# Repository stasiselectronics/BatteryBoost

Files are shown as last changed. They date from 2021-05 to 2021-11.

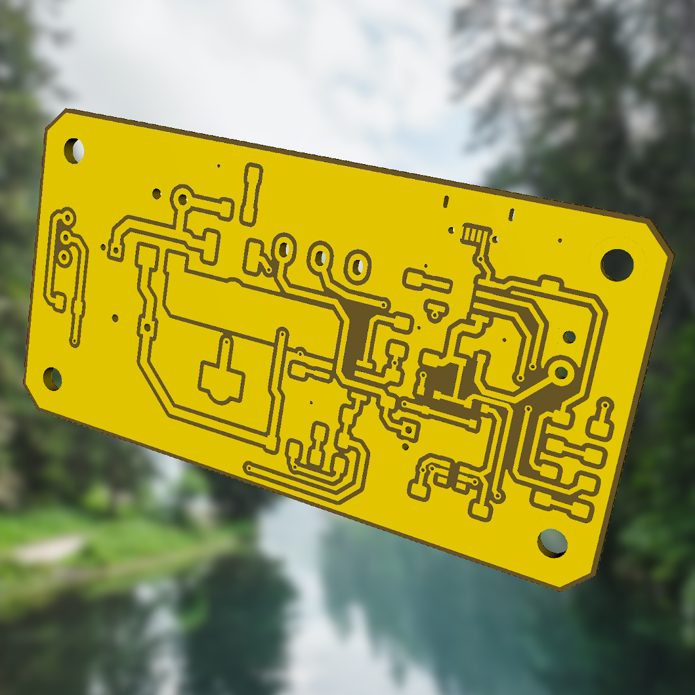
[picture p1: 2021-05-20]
Images/Renders/2021.05.17/2021_05_17_4.png

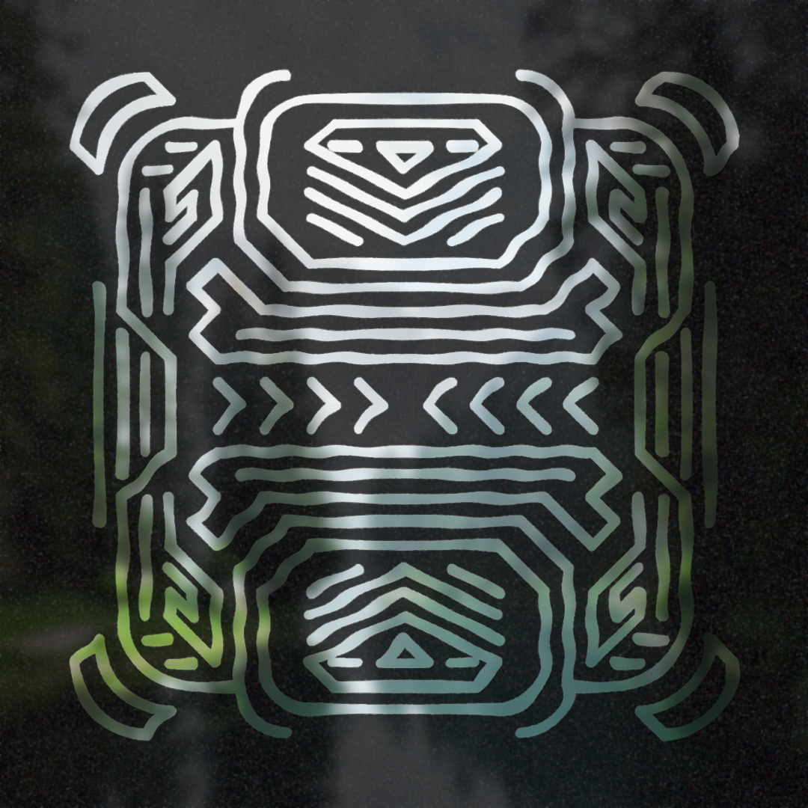
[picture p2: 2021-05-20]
Images/Renders/2021.05.17/2021_05_17_0.png

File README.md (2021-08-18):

# Battery Boost Module
<h3>3.7 V input, 5V-24V output</h3>

This respository contains the source files for a boost circuit designed to boost the voltage from a lithium battery to anywhere between 5 and 24 Volts.

The module includes a battery management system to help make recharging as easy as plugging in the microUSB cable.

## KiCAD

This board has been designed in KiCAD, the wonderful open-source Electronics CAD software!

[Learn More About KiCAD](https://www.kicad.org/about/kicad/)

## Project Status

I have written an [article on Hackster](https://www.hackster.io/stasiselectronics/lithium-battery-voltage-boost-module-5ba98e) to explain some of the lessons learned while working on this design.

I still have some testing to do and write about, so stay tuned for that!

I also intend on creating a documentation companion site hosted on this repo's github page.

Be sure to check out my instagram page for more frequent updates!

[Stasis Electronics on Instagram](https://www.instagram.com/stasis.electronics/)

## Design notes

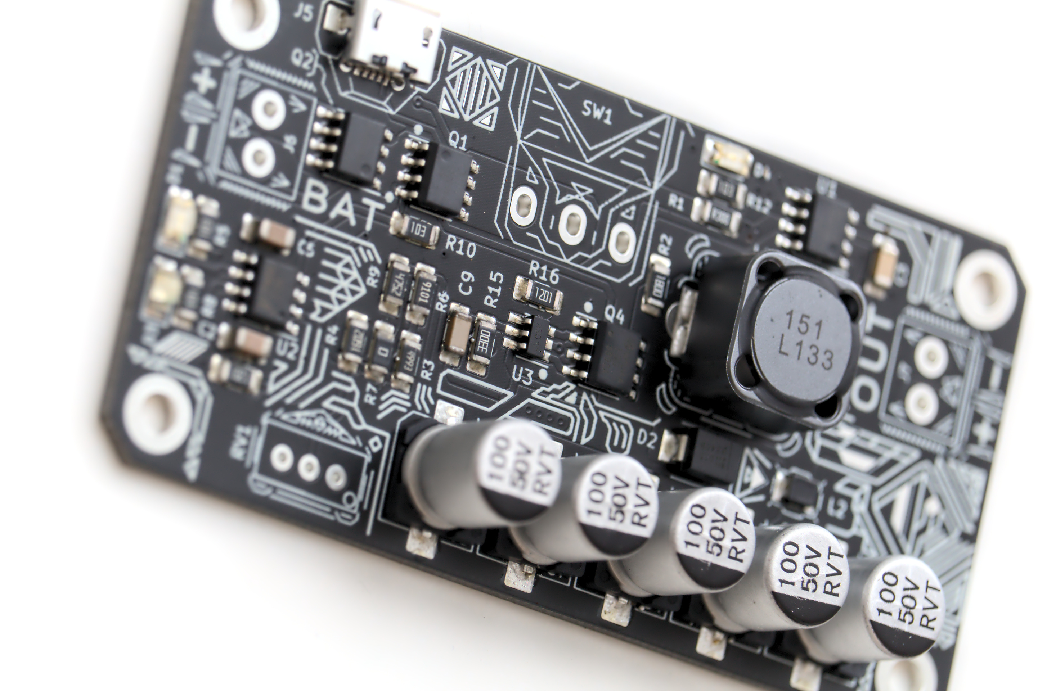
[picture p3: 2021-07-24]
Images/Photograpsh/A02.jpg

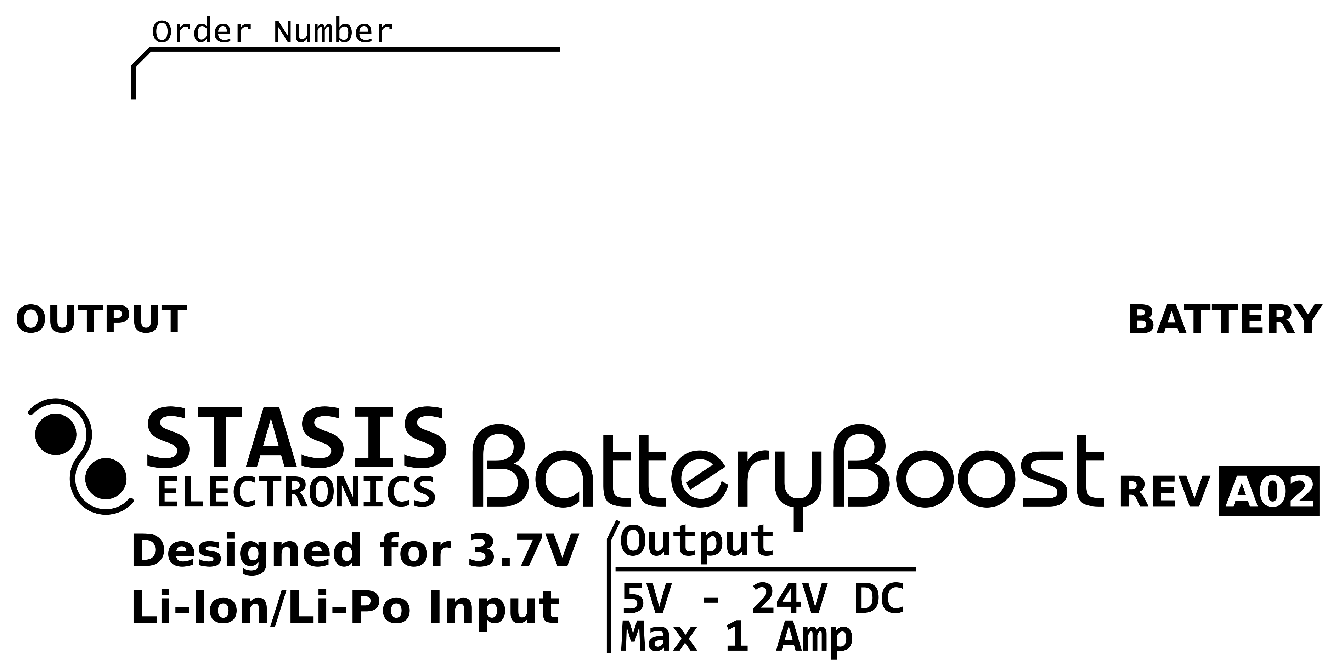
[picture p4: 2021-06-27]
Output Files/Artwork Files/B_Artwork.png

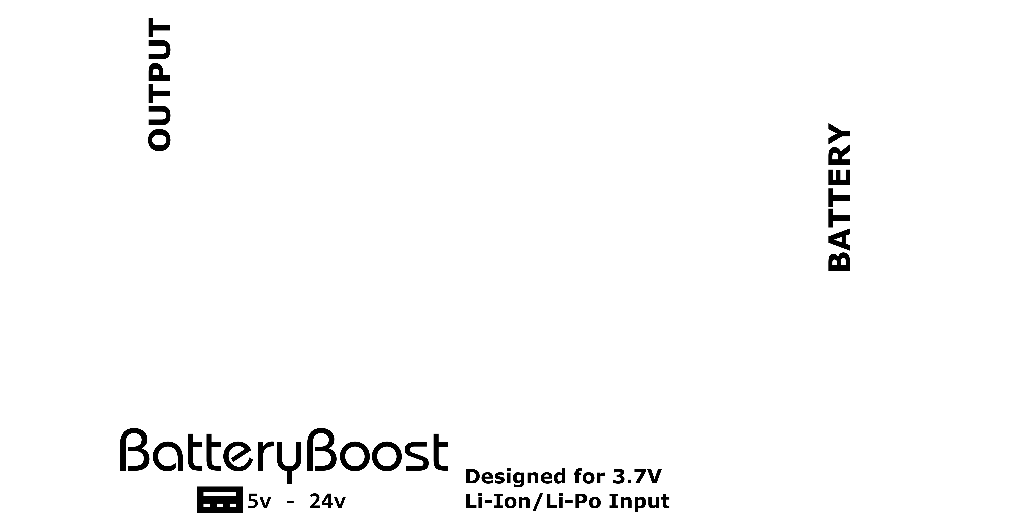
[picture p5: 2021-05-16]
Output Files/Artwork Files/F_Artwork.png

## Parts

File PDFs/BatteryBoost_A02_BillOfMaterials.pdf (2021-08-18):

## github.com/stasiselectronics tindie.com/stores/stasis/ @stasis.electronics

## Bill of Materials

08/18/2021

## 1 of 1

# Battery Boost Bill Of Materials

# PCBA Revision A02

Item Qty | Designator | Value | Part 1 MF | Part 1 MPN
1 | 1 | C3 | 1.5nF ±10% 50V X7R 1206 | YAGEO | CC1206KRX7R9BB152 | ☐
2 | 1 | C9 | 100nF ±10% 50V X7R | YAGEO | CC1206KRX7R9BB104 | ☐
3 | 5 | C1 C4 C6 C7 C8 | 100uF ±20% 50V | Honor Elec | RVT1H101M0810 | ☐
4 | 2 | C2 C5 | 10uF ±10% 25V X5R | Samsung Electro-Mechanics | CL31A106KAHNNNE | ☐
5 | 1 | D2 | 40V 3A 500mV@3A | Diodes Incorporated | B340B-13-F | ☐
6 | 2 | D1 D4 | Green LED | EKINGLUX | E6C1206VGAC1UDA | ☐
7 | 1 | D3 | Orange LED | EKINGLUX | E6Q1206SEAC1UDA | ☐
8 | 2 | J6 J7 | Screw Terminal | Ningbo Kangnex Elec | WJ124-3.81-2P | ☐
9 | 1 | J5 | Micro USB Connector | Korean Hroparts Elec | U-F-M5DD-Y-L | ☐
10 | 1 | L1 | 150uH ±20% 2.15A 280mΩ | Sumida | CDRH127/LDNP-151MC | ☐
11 | 1 | L2 | 1uH ±20% 3.29A 59mΩ | Sunltech Tech | SLO252012F1R0MTT | ☐
12 | 2 | Q1 Q2 | -30V 12A 14mΩ @ 8A | Diodes Incorporated | DMP3020LSS-13 | ☐
13 | 1 | Q4 | 20V 7.5A 24mΩ @ 2.5Vgs | ON Semiconductor | FDS6892A | ☐
14 | 1 | R7 | 0R | YAGEO | RC1206FR-070RL | ☐
15 | 1 | R1 | 0.3R | UNI-ROYAL | 1206W4F300LT5E | ☐
16 | 1 | R2 | 180R | YAGEO | RC1206FR-07180RL | ☐
17 | 4 | R5 R8 R10 R12 | 10k | YAGEO | RC1206JR-0710KL | ☐
18 | 1 | R4 | 16k | YAGEO | RC1206FR-0716KL | ☐
19 | 2 | R11 R16 | 1.2kΩ ±1% 0.25W | YAGEO | RC1206FR-071K2L | ☐
20 | 1 | R15 | 330R ±1% 0.25W | YAGEO | RC1206FR-07330RL | ☐
21 | 1 | R9 | 47.5kΩ ±1% 0.25W | YAGEO | AC1206FR-0747K5L | ☐
22 | 1 | R3 | 499k 1% 0.25W | UNI-ROYAL | 1206W4F4993T5E | ☐
23 | 1 | R6 | 9.1k 1% 0.25W | RALEC | RTT069101FTP | ☐
24 | 1 | RV1 | Variable Resistor 500kΩ ±10% | BOCHEN | 3296W-1-504 | ☐
25 | 1 | SW1 | ##V ##A SPST Switch | XKB Connectivity | SS-12D06L5 | ☐
26 | 1 | U1 | Boost Converter IC | Diodes Incorporated | AP34063S8G-13 | ☐
27 | 1 | U3 | Battery Protection IC | Diodes Incorporated | AP9101CK6-AYTRG1 | ☐
28 | 1 | U2 | Battery Charger IC | TOPPOWER | TP4056-42-ESOP8 | ☐

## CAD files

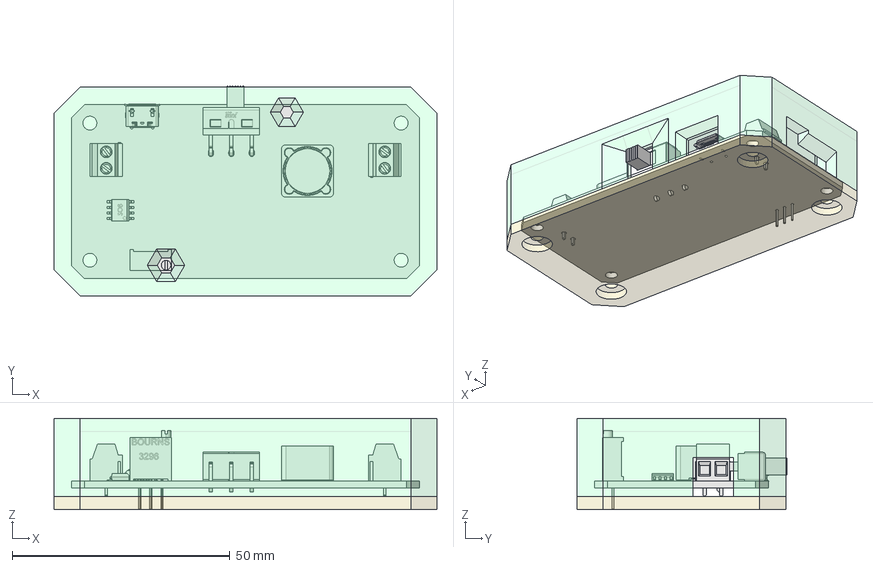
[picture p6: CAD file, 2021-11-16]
Enclosure Files/Draft_Enclosure.FCStd
88.0 x 48.3 x 21.0 mm
BatteryBoost_sp

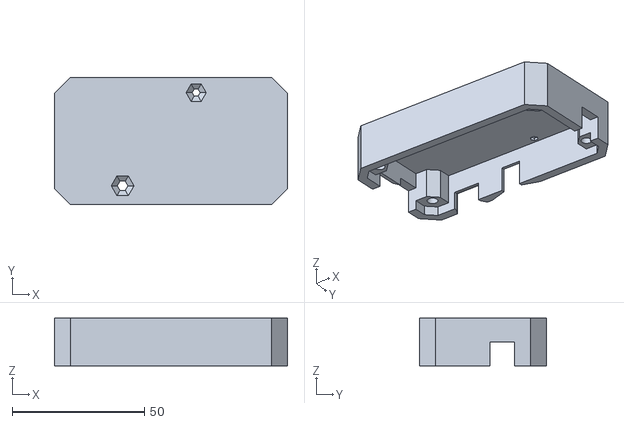
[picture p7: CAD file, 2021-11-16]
Enclosure Files/STLs/BatteryBoost_Enclosure_Top.stl
88.0 x 48.0 x 18.0

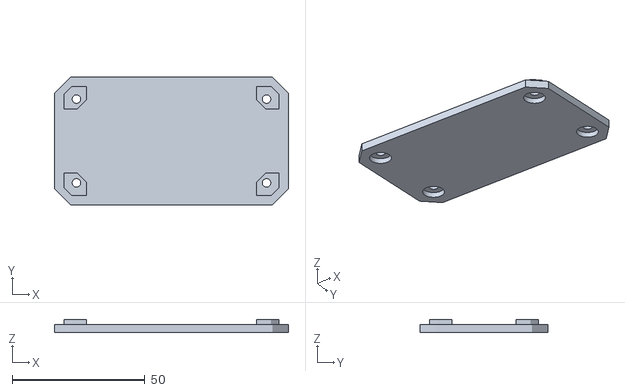
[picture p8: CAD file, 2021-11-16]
Enclosure Files/STLs/BatteryBoost_Enclosure_Bottom.stl
88.0 x 48.0 x 5.00

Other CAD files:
Enclosure Files/PCB_Assembly.FCStd

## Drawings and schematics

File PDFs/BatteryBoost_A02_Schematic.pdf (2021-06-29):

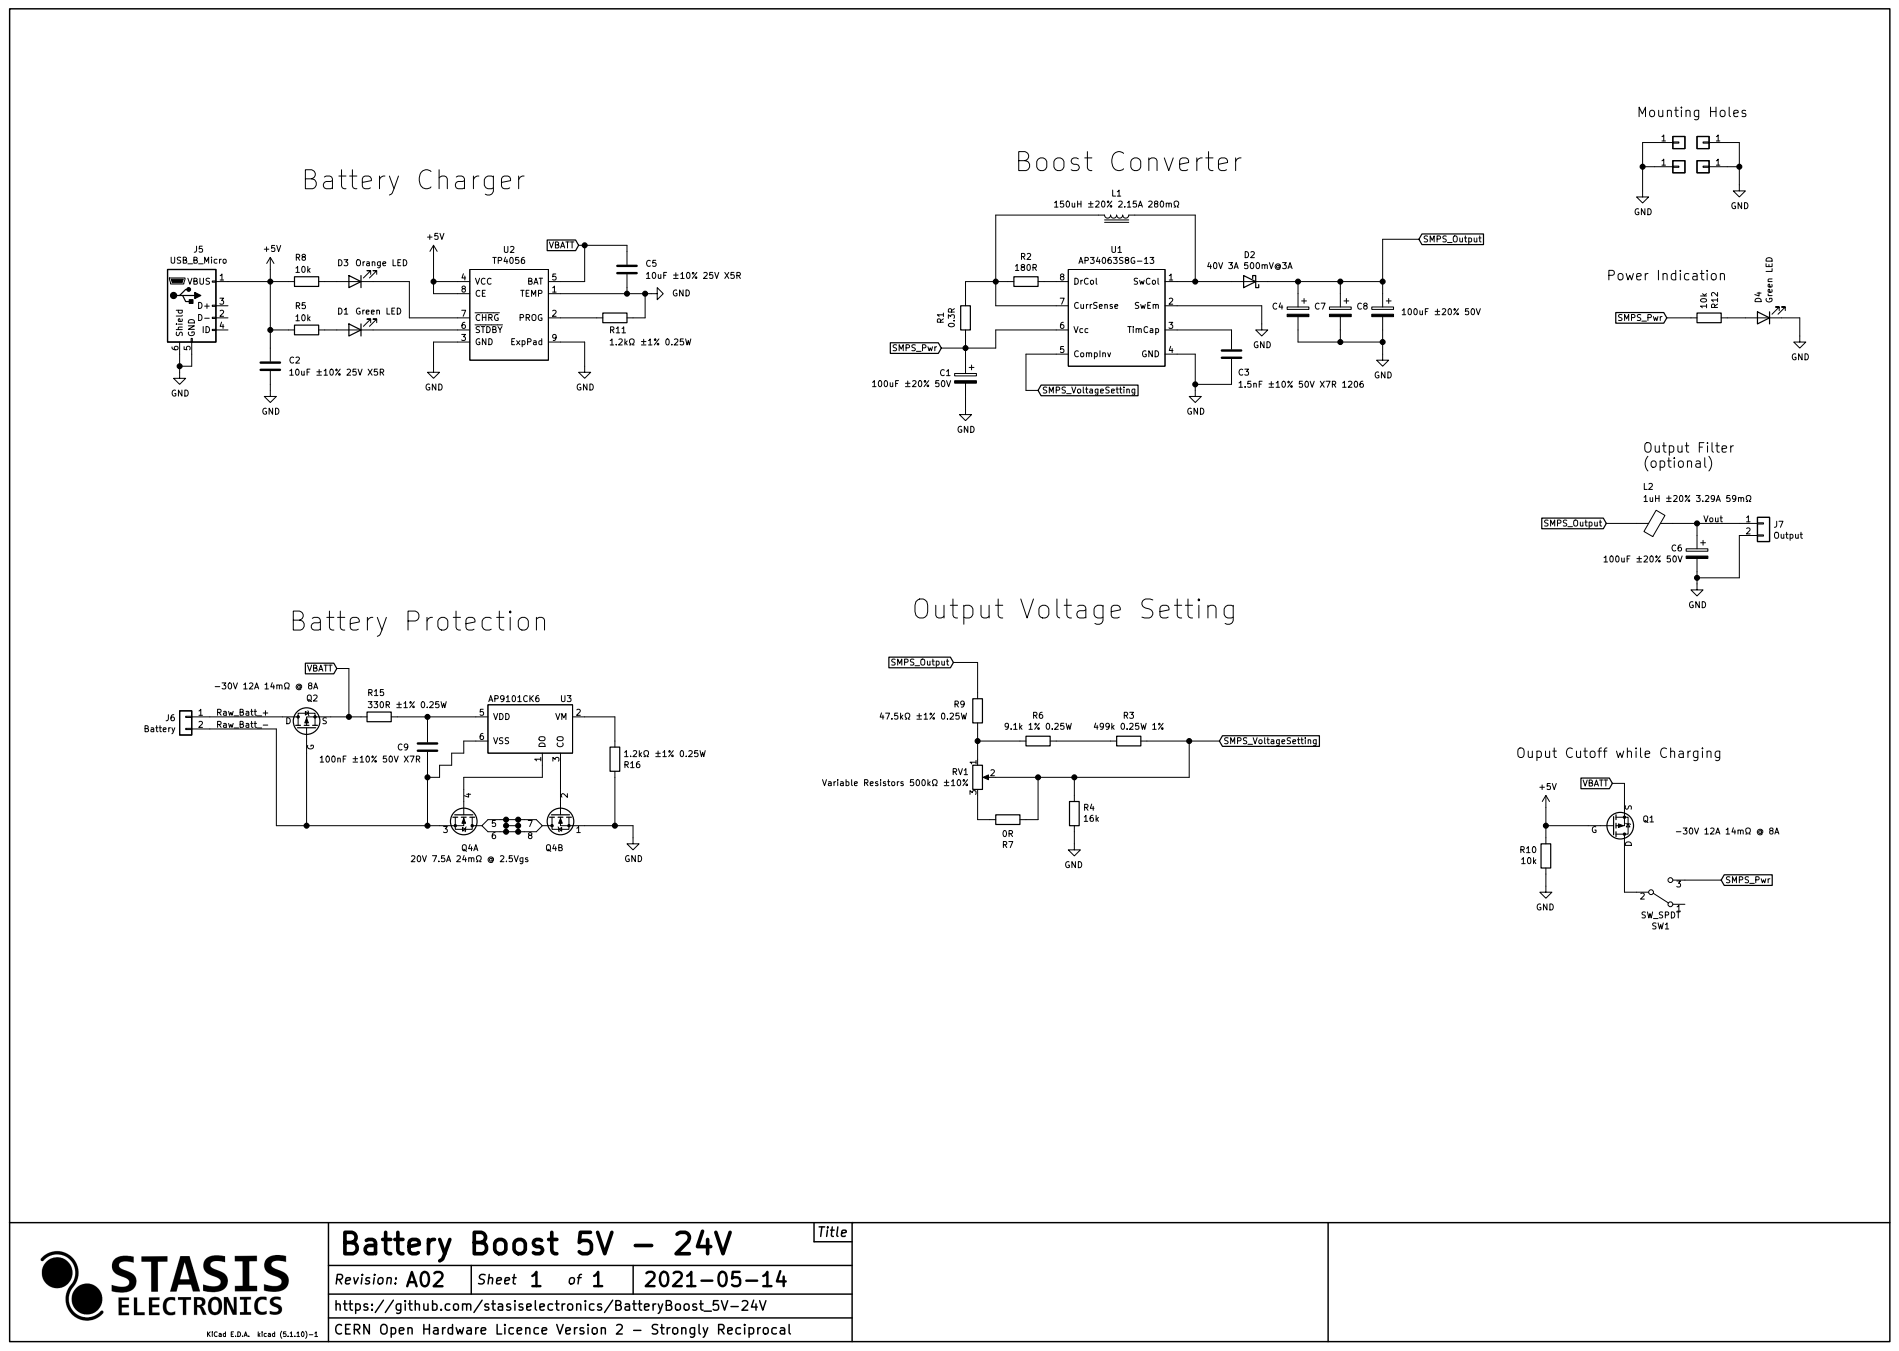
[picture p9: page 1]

Ouput Cutoff while Charging

Revision:
https://github.com/stasiselectronics/BatteryBoost_5V-24V

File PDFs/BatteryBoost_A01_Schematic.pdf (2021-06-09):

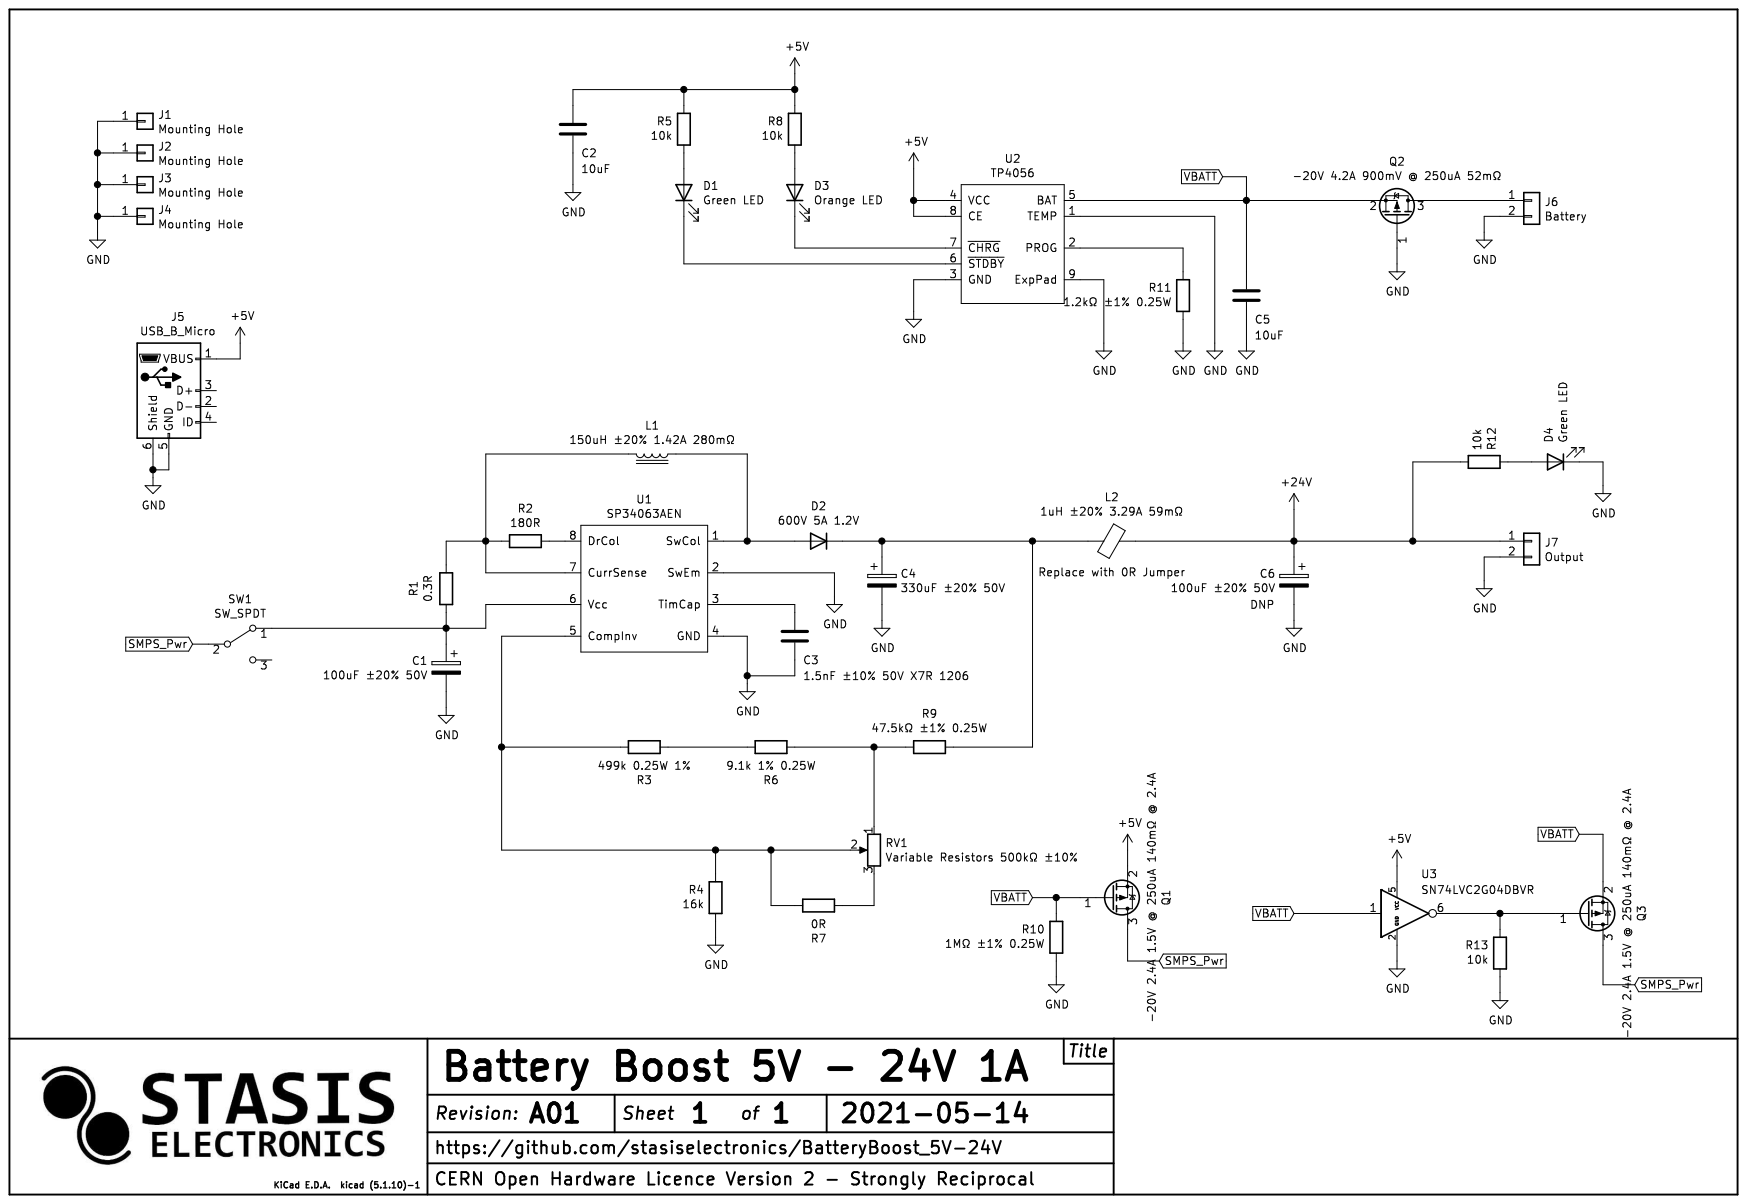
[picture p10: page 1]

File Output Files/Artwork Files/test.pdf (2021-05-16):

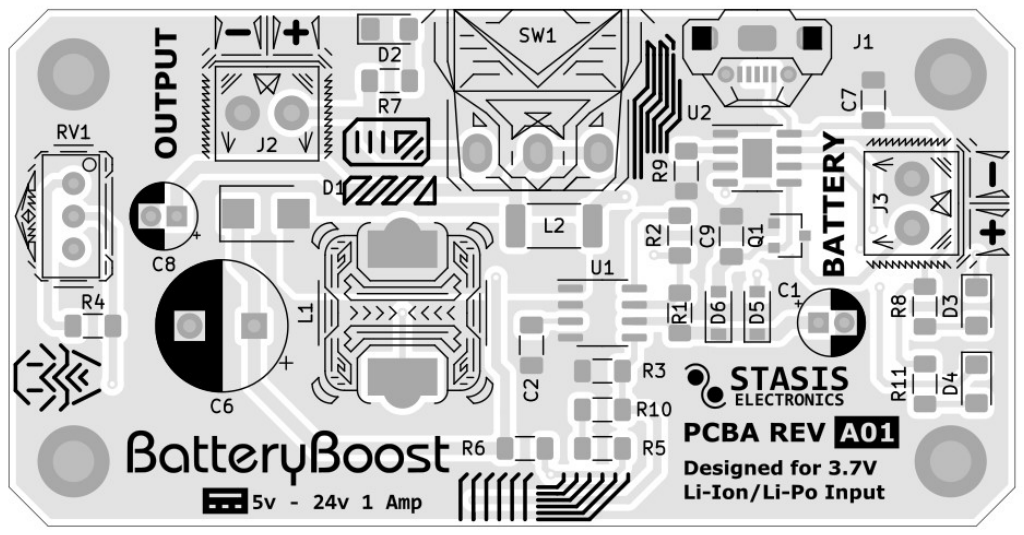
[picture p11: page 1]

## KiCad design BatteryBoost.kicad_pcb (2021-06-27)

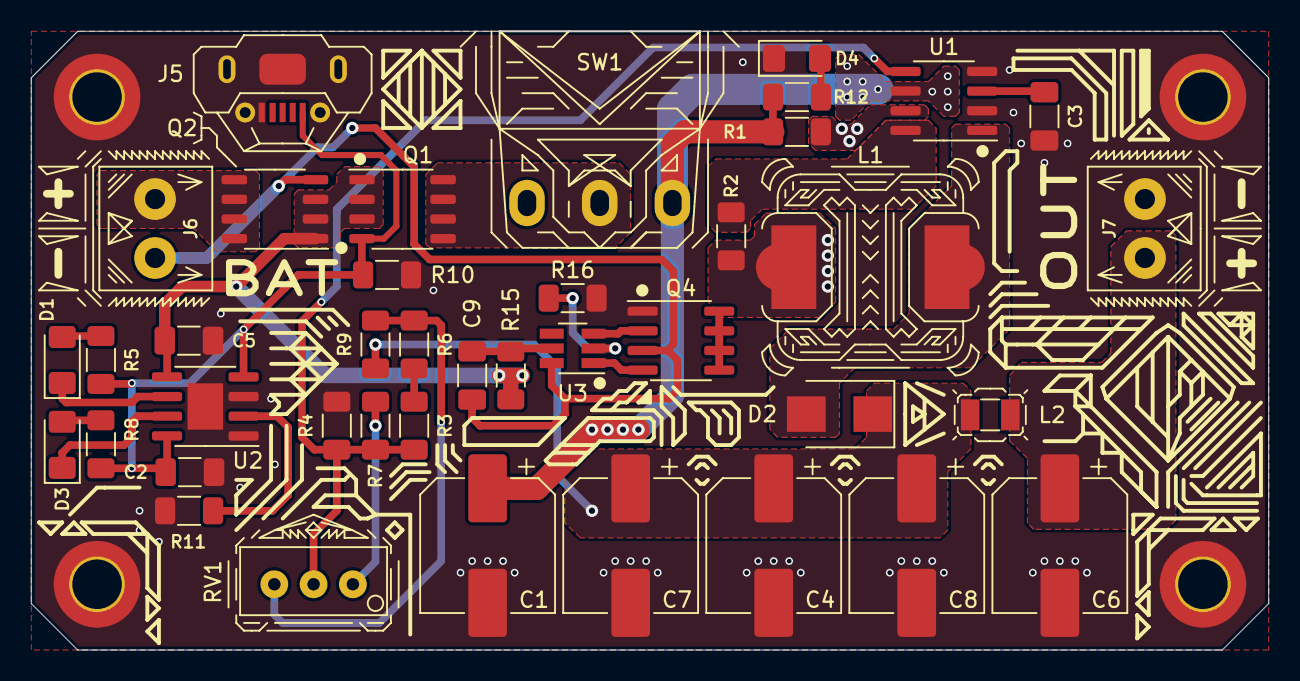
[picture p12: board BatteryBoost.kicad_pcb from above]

Board: 2 copper layers, 80.0 x 40.0 mm, 44 parts (0 on the bottom side), 28 nets.

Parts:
C1, C4, C6, C7: 100uF ±20% 50V; CP_Elec_8x10.5
C2, C5: 10uF ±10% 25V X5R; C_1206_3216Metric_Pad1.33x1.80mm_HandSolder
C3: 1.5nF ±10% 50V X7R 1206; C_1206_3216Metric_Pad1.33x1.80mm_HandSolder
C8: 100uF ±20% 50V (x3); CP_Elec_8x10.5
C9: 100nF ±10% 50V X7R; C_1206_3216Metric_Pad1.33x1.80mm_HandSolder
D1, D4: Blue LED; D_1206_3216Metric_Pad1.42x1.75mm_HandSolder
D2: 40V 3A 500mV@3A; D_SMB
D3: Red LED; D_1206_3216Metric_Pad1.42x1.75mm_HandSolder
J1, J2, J3, J4: Mounting Hole; MountingHole_3.2mm_M3_DIN965_Pad_TopBottom
J5: USB_B_Micro; U-F-M5DD-Y-L
J6: Battery; WJ124-3.81-2P
J7: Output; WJ124-3.81-2P
L1: 150uH ±20% 2.15A 280mΩ; Inductor_SLH_12x12x8_HandSolder
L2: 1uH ±20% 3.29A 59mΩ; L_2.5x2.0_Hand_Solder
Q1: -40V 7.5A 2.5V @ 250uA 40mΩ @ 6A; SOP-8_3.9x4.9mm_P1.27mm
Q2: -40V 7.5A 40mΩ @ 6A; SOP-8_3.9x4.9mm_P1.27mm
Q4: 20V 7.5A 24mΩ @ 2.5Vgs; SOIC-8_3.9x4.9mm_P1.27mm
R1: 0.3R; R_1206_3216Metric_Pad1.30x1.75mm_HandSolder
R2: 180R; R_1206_3216Metric_Pad1.30x1.75mm_HandSolder
R3: 499k 0.25W 1%; R_1206_3216Metric_Pad1.30x1.75mm_HandSolder
R4: 16k; R_1206_3216Metric_Pad1.30x1.75mm_HandSolder
R5, R8, R10, R12: 10k; R_1206_3216Metric_Pad1.30x1.75mm_HandSolder
R6: 9.1k 1% 0.25W; R_1206_3216Metric_Pad1.30x1.75mm_HandSolder
R7: 0R; R_1206_3216Metric_Pad1.30x1.75mm_HandSolder
R9: 47.5kΩ ±1% 0.25W; R_1206_3216Metric_Pad1.30x1.75mm_HandSolder
R11, R16: 1.2kΩ ±1% 0.25W; R_1206_3216Metric_Pad1.30x1.75mm_HandSolder
R15: 330R ±1% 0.25W; R_1206_3216Metric_Pad1.30x1.75mm_HandSolder
RV1: Variable Resistors 500kΩ ±10%; Potentiometer_3296W-1-504
SW1: SW_SPDT; Switch_SS-12D06L5
U1: SP34063AEN; SOIC-8_3.9x4.9mm_P1.27mm
U2: TP4056; SOIC-8-1EP_3.9x4.9mm_P1.27mm_EP2.29x3mm
U3: AP9101CK6; SOT-23-6_Handsoldering

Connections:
+5V: C2.1, J5.1, Q1.G, R5.2, R8.1, R10.2, U2.4, U2.8
/Raw_Batt_+: J6.1, Q2.D
/Raw_Batt_-: C9.2, J6.2, Q2.G, Q4.3, U3.6
/Vout: C6.1, J7.1, L2.2
GND: C1.2, C2.2, C3.2, C4.2, C5.2, C6.2, C7.2, C8.2, D4.1, J1.1, J2.1, J3.1, J4.1, J5.5, J5.6, J7.2, Q4.1, R4.1, R10.1, R11.2, R16.2, U1.2, U1.4, U2.1, U2.3, U2.9
unnamed: C3.1, U1.3
unnamed: C9.1, R15.2, U3.5
unnamed: D1.1, U2.6
unnamed: D1.2, R5.1
unnamed: D2.2, L1.1, U1.1
unnamed: D3.1, U2.7
unnamed: D3.2, R8.2
unnamed: D4.2, R12.2
unnamed: L1.2, R1.1, R2.2, U1.7
unnamed: Q1.D, SW1.2
unnamed: Q4.2, U3.3
unnamed: Q4.4, U3.1
unnamed: Q4.5, Q4.6, Q4.7, Q4.8
unnamed: R2.1, U1.8
unnamed: R3.2, R6.1
unnamed: R6.2, R9.1, RV1.1
unnamed: R7.1, RV1.3
unnamed: R11.1, U2.2
unnamed: R16.1, U3.2
SMPS_Output: C4.1, C7.1, C8.1, D2.1, L2.1, R9.2
SMPS_Pwr: C1.1, R1.2, R12.1, SW1.3, U1.6
SMPS_VoltageSetting: R3.1, R4.2, R7.2, RV1.2, U1.5
VBATT: C5.1, Q1.S, Q2.S, R15.1, U2.5

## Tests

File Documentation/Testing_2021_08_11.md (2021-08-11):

# Oh man was I surprised
I recently tested the A02 BatteryBoost boards and learned something very important when it comes to designing switch mode power supplies.

Switch Current is not the same thing as Output Current of the Power Supply you are designing.

I was expecting to get 1 Amp out of the board from the input voltage supply. I was actually getting around 120 mA at around 12 V when the converter IC is set to 24 V.

The board is experiencing significant voltage derating when loaded due to what I believe is the current limiting function of the converter IC. If the input voltage is raised, the output voltage will go up some, and if the load is decreased this will also raise the output voltage.  

After some searching around the internet, I came across some application notes that might have some detailed information.

For further information refer to Application Note AN920A/D and AN954/D.
[source](https://www.sparkfun.com/datasheets/IC/MC34063A.pdf)

AN920A/D 
Theory and Applications of the MC34063 and A78S40 Switching Regulator Control Circuits
ONSEMI
[link](https://www.onsemi.com/pub/Collateral/AN920-D.PDF)

AN954/D
Transformerless Power Supplies: Resistive and Capacitive
Microchip
[link](http://ww1.microchip.com/downloads/en/AppNotes/00954A.pdf)

I should try and calculate the maximum current that can be drawn at 24 Volts before derating happens.

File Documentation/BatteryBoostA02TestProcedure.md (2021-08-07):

# Test Procedure
<h2> Checking functionality and exploring limits </h2>

As the BatteryBoost project has moved forward, I have been testing features and functionality ad hoc. That is, I have been testing things as I go. This means that I have bits and pieces of information floating around my head and maybe some written notes.

I want to try and do something a bit better. I want to outline the testing that I need to do in order to feel confident enough to sell units of this board. 

For this prototype, I want to demonstrate the the design fulfills its requirements.

The overall functionality that I wish to demonstrate, is that the board can safely discharge a 3.7 V Lithium battery (Ion or Polymer) at the max output of 24 Volts at 1 Amp. 

We will also see if the board can exceed that without damage or failure. 

## Before Power On

There are two major systems operating on this board: Battery Management and Boost Conversion. The former focuses on keeping the battery healthy

But first things first, let's make sure that the board has no shorts to ground.

## Turning on the power

Let's connect a bench top power supply set to 3.7 Volts and current limited to 0.150 mA. This is to keep the power supply from letting too much power into the board if something is wrong. We can increase the current limit as the testing requires. 

No load at the moment. 

Make sure the switch is "OFF"

1. Set the output resistor for max voltage output
2. Power it on and see how much power it consumes in standby
3. flick the switch and turn on the output voltage
4. measure the output voltage without a load
5. sweep input voltage between 3.0 and 4.2 Volts

**Table 1 : Output Voltage vs Input Voltage under no load**
| Set Input Voltage | Measured Output Voltage |
|--|--|
| 3.0 |  |
| 3.1 |  |
| 3.2 |  |
| 3.3 |  |
| 3.4 |  |
| 3.5 |  |
| 3.6 |  |
| 3.7 |  |
| 3.8 |  |
| 3.9 |  |
| 4.0 |  |
| 4.1 |  |
| 4.2 |  |

## Finding max load

Now that we know that the boost conversion works, it is time to determine what the maximum load is. 

A programmable load will help make it easy to adjust the output current. Another alternative is to use appropriately rated power resistors. 

| Set Output Current | Measure Output Voltage| Calculate Output Power |
|--|--|--|
| 200 mA |  |  |
| 600 mA |  |  |
| 800 mA |  |  |
| 1 A |  |  |
| 1.5 A |  |  |
| 1.75 A |  |  |

Temperature? We need to make sure the board isn't getting too hot.

What protection features are there that need to be tested?

- Voltage of 150 mV or more over the current sense resistor should shutdown the boost converter. However, this needs to be tested to see what happens.
- A voltage of 120 mV or more over the two mosfets should trip the over discharge protection on the battery charger IC.

# Test Procedure

How do we know our design fulfills the requirements? We test it!

For simple designs this can be as straight forward as powering it on and seeing that it functions.

However, for more complex designs it could require rigorous testing to verify the full functionality. This is especially the case when it comes to the professional engineering world, where documentation and full validation can be required by the customer or management.

I am not a test engineer, however I sometimes find myself writing test procedures at work. I still have a lot to learn in this area, and want to use this project as a way to gain more experience.

## BatteryBoost

For this design, there are two major areas that need testing: Battery Management and Voltage Boost Conversion. 

Each of these areas has their own mechanisms that need to be verified. For a more in depth look at these systems, check out the [documentation](TODO) or the [source files](TODO).

I will also break the testing into smaller parts to help organize the documentation.

## Test Equipment
What tools do we need and how do we use them?

- Multimeter
- Programmable Load
- Programmable Power Supply

### Before Powering On

Here we begin to look at the assembled board before we turn anything on. This way we can inspect the design without the risk of damaging our test equipment, our benches, or ourselves.

A visual inspection can include looking for all sorts of things. There are the obvious issues like defects in assembly (think unmounted components, improperly mounted components, poor soldering, etcetera). 

There are less obvious issues that could be seen from a visual inspection, like components that are mounted in the wrong orientation ("Pin 1" markings help to make this easier to spot), or components that are not what you ordered. Things can get mixed up when someone is assembling boards, so the wrong value of parts could be mounted. 

A quick visual inspection can help to make sure the obvious issues are caught, and a detailed visual inspection could help verify the assembly is exactly what you ordered (or what you designed).

#### Shorts and Opens

Measure resistance between the following
1. GND and Bat+
2. GND and VBATT
3. GND and 5V
4. GND and SMPS_OUTPUT

### Battery Management

Within the battery management circuit, there are a few subsytems that need attention.

#### Charge Control

The lithium batteries are charged using the common TP4056 IC. It will be able to monitor the voltage of the battery and react according to certain conditions.

What are the functions of the TP4056 that need to be tested?

	- Charging the battery
	- LED indication
#### Battery Protection

	- Reverse Polarity Protection
	- Over current
	- Undervoltage lockout
 
### Boost Converter

The boost converter has been claiming a current of 1.5 Amps. I want to test this at 24 Volts. Can I get that out of a 3.7 Volt input?

Testing output voltage:
1. Set the resistor to its lowest resistance
2. Measure equivalent resistance
3. Calculate the output voltage that it would create
4. Set the resistor to its highest resistance
5. Measure equivalent resistance
6. Calculate the output voltage that it would create

Now that we know that we can create the voltages that we want (5:24) Volts, we can start giving the board some power.

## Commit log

2021-05-14 add files from fume extractor project
    [BatteryBoost.kicad_pcb, BatteryBoost.sch]
2021-05-14 update schematic and layout
    [BatteryBoost.kicad_pcb, BatteryBoost.sch]
2021-05-14 add chamfer to board edge
    [BatteryBoost.kicad_pcb]
2021-05-15 finalize designs
    [BatteryBoost.kicad_pcb, BatteryBoost.sch]
2021-05-15 Finalize schematic and layout
    [BatteryBoost.kicad_pcb, BatteryBoost.sch]
2021-05-16 A01 Release Files
    [BatteryBoost-B_Cu.gbr, BatteryBoost-B_Mask.gbr, BatteryBoost-B_SilkS.gbr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]
2021-05-16 Rename Fabrication Release Archive
    [BatteryBoost.sch]
2021-05-20 add render images from KiCAD
2021-06-08 change D2 to Schottky Barrier Diode for faster recovery time
    [BatteryBoost.sch]
2021-06-08 Change source select method to diode array
    [BatteryBoost.sch]
2021-06-08 update power inductor to 2.15 A version
    [BatteryBoost.sch]
2021-06-09 Add Schematic for revision A01
2021-06-09 Re-arrange schematic
    [BatteryBoost.sch]
2021-06-09 Update schematic revision to A02
    [BatteryBoost.sch]
2021-06-09 Change source selection method
    [BatteryBoost.sch]
2021-06-09 Clear board
    [BatteryBoost.kicad_pcb]
2021-06-09 update board size to 80x40mm
    [BatteryBoost.kicad_pcb]
2021-06-09 update component part info
    [BatteryBoost.sch]
2021-06-10 Start placing footprints on board
    [BatteryBoost.kicad_pcb, BatteryBoost.sch]
2021-06-10 Add PMOS footprint and symbol
2021-06-17 Add battery protection circuit
    [BatteryBoost.kicad_pcb, BatteryBoost.sch]
2021-06-17 Preliminary placement for protection circuit
    [BatteryBoost.kicad_pcb, BatteryBoost.sch]
2021-06-18 remove BJT power indication
    [BatteryBoost.sch]
2021-06-18 remove BJT circuit layout
    [BatteryBoost.kicad_pcb]
2021-06-21 Change schematic to A3 size
    [BatteryBoost.sch]
2021-06-21 Update net names
    [BatteryBoost.kicad_pcb]
2021-06-21 Add footprint for filter inductor
    [BatteryBoost.kicad_pcb]
2021-06-21 Add new filter inductor footprint
    [BatteryBoost.kicad_pcb, BatteryBoost.sch]
2021-06-21 place and route battery protection circuit
    [BatteryBoost.kicad_pcb]
2021-06-21 move potentiometer
    [BatteryBoost.kicad_pcb]
2021-06-22 Add artwork and finalize layout
    [BatteryBoost.kicad_pcb]
2021-06-27 Fix 9.1k Resistor order code
    [BatteryBoost.sch]
2021-06-27 Update routing
    [BatteryBoost.kicad_pcb]
2021-06-27 finalize bottom artwork
    [BatteryBoost.kicad_pcb]
2021-06-27 Add A02 Fabrication Files
    [BatteryBoost-B_Cu.gbr, BatteryBoost-B_Mask.gbr, BatteryBoost-B_SilkS.gbr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]
2021-06-27 Update fabrication files
    [BatteryBoost-B_Cu.gbr, BatteryBoost-B_Mask.gbr, BatteryBoost-B_SilkS.gbr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]
2021-06-27 Update part info for sourcing issues
    [BatteryBoost.kicad_pcb, BatteryBoost.sch]
2021-06-29 Add A02 Schematic
2021-07-23 add bill of materials for A02
    [BatteryBoost A02 BOM.ods]
2021-07-26 Update Bill of Materials
    [BatteryBoost A02 BOM.ods]
2021-08-18 add BOM as pdf
2021-11-15 Add FreeCAD files
    [Draft_Enclosure.FCStd, PCB_Assembly.FCStd]
2021-11-15 update enclosure files
    [Draft_Enclosure.FCStd, PCB_Assembly.FCStd]
2021-11-16 fix clearance for main switch and update STLs
    [BatteryBoost_Enclosure_Bottom.stl, BatteryBoost_Enclosure_Top.stl, Draft_Enclosure.FCStd]

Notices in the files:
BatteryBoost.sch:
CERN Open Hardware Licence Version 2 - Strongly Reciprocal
